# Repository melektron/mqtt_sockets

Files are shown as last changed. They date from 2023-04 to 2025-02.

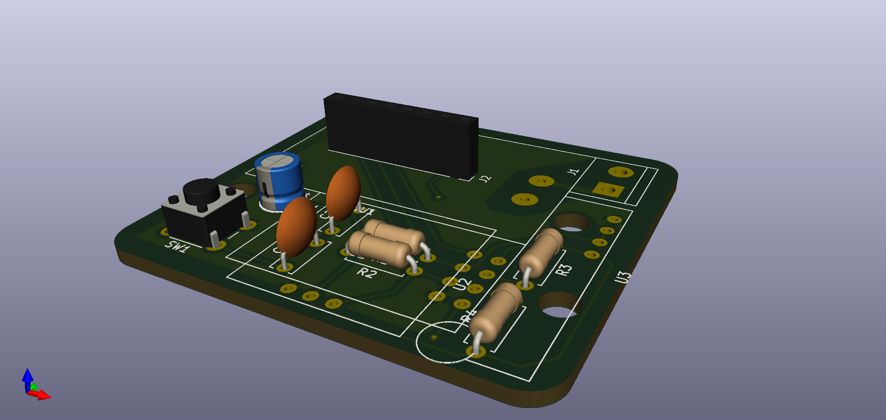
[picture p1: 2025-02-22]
hardware/WiFi-RC-Switch-Bridge_Outlet/WiFi-RC-Switch-Bridge_Outlet.png

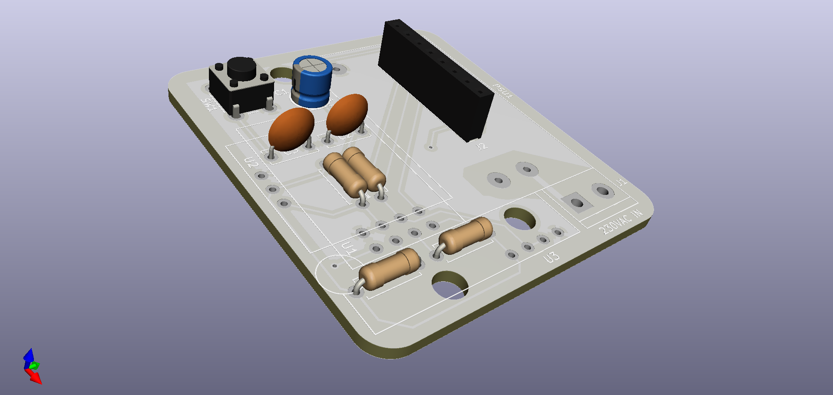
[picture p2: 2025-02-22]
hardware/WiFi-RC-Switch-Bridge_Outlet/WiFi-RC-Switch-Bridge_Outlet3.png

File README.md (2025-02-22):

# Disclaimer

This is a PlatformIO "port" of an old of an old ESP8266 Arduino project that I did several years ago.
This code is by no means clean or memory safe and there are no guarantees of it working as expected. The only reason this old project is published in this state is so I can preserve it and fix bugs that arise over time as I need this in daily production. It has been working mostly reliably but use it at your own risk. 

Note to myself:
The folder "old_code" contains all the old code and versions that came about before I used git to store the project. These are just here for historical purposes and are not to be used. 

# MQTT Sockets

This project allows an ESP8266 connected to an MQTT server through WiFi and take commands from a SmartHome system like HomeAssistant. It then parses these commands and switches 433 MHz Remote controlled sockets on or off using a 433 MHz transmitter connected to the ESP. Multiple Remote-Socket protocols are supported.

## Project structure

This is a PIO project, so it has all the usual code folders. Additionally, the ```hardware``` folder contains KiCAD projects (legacy KiCAD project structure as these are old files):
- ```hardware/WiFi-RC-Switch-Bridge_Outlet```: The main PCB containing the ESP, RF-Transceivers and an integrated AC power supply for powering the board from the wall. This is what was used in the end.
- ```hardware/WiFi-RC-Switch-Bridge_USB```: At one point there was a plan to create a version of the board powered by USB. This contains the KiCAD project for that, although it was never completed.
- ```hardware/WiFi-RC-Switch-Programmer```: A USB-to-UART adapter based on CH340G to flash the ESP on the board. This has a connector matching the pinout of the header on the main PCB. Over the years, this has been used for many other projects and purposes.

## Setup

To use the project, you need to specify WIFI secrets, fingerprints and other configuration in the ```include/secrets.h``` file. Example content:

```c
#pragma once

#define WIFI_SSID "MyHomeWifi"
#define WIFI_PSK "MyWiFiPassword"

#define MQTT_SERVER "192.168.1.13"
#define MQTT_PORT 1883
// generate the fingerprint on the server using this command:
// echo | openssl s_client -connect localhost:1883 | openssl x509 -fingerprint -noout
#define MQTT_FINGERPRINT "07 ED 59 67 2C CD 31 6C EF 27 F7 AC 38 02 07 9C 60 EC FA 0A" // this isn't used at the moment because it didn't work
#define MQTT_BASE_TOPIC "/devices/sub0/espdev2051a/"
#define MQTT_USER "deviceuser"
#define MQTT_PWD  "devicepwd"

// when using DHCP do the following
#define WIFI_DHCP

// when using static IP do the following (replace with your correct IP settings)
// when WIFI_DHCP is defined, these values are ignored
#define WIFI_STATIC_IP 192,168,1,122
#define WIFI_STATIC_ROUTER 192,168,1,1
#define WIFI_STATIC_NETMASK 255,255,255,0

```

Of course, all the information has to be replaced by data applicable to your network setup.

Note to myself:
The values needed for my setup are found in the infrastructure setup notes.

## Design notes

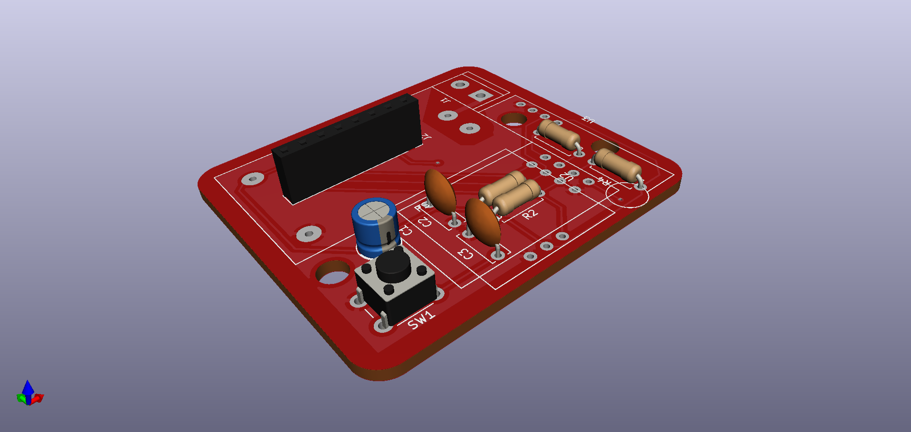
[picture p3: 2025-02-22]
hardware/WiFi-RC-Switch-Bridge_Outlet/WiFi-RC-Switch-Bridge_Outlet2.png

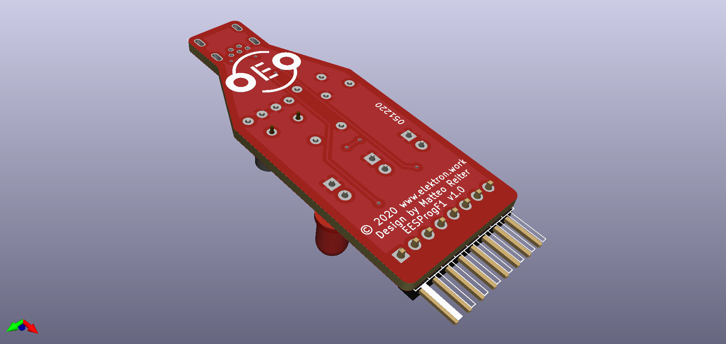
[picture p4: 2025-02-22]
hardware/WiFi-RC-Switch-Programmer/WiFi-RC-Switch-Programmer2.png

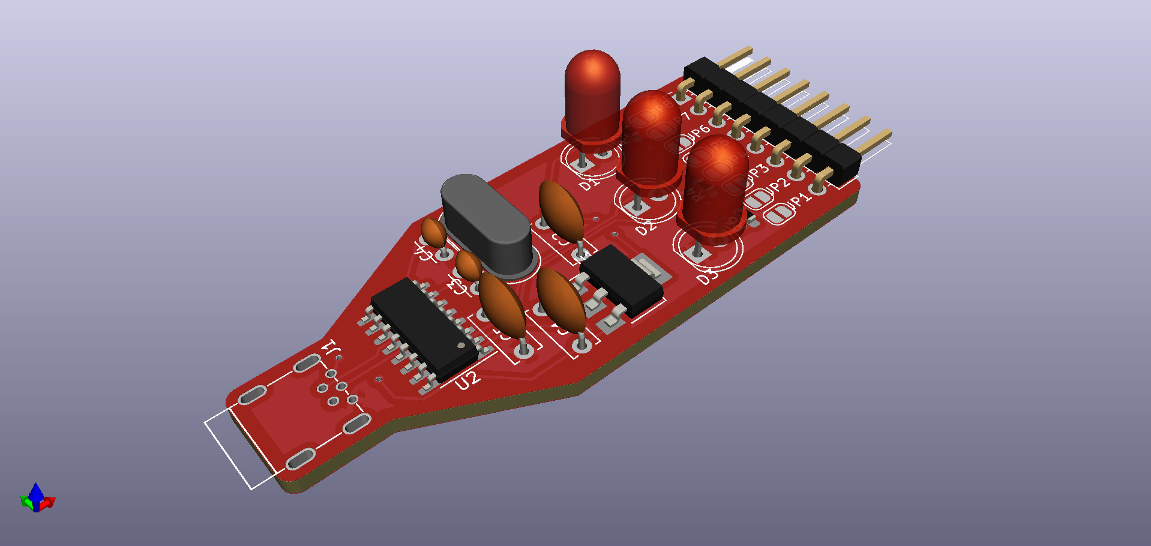
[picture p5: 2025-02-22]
hardware/WiFi-RC-Switch-Programmer/WiFi-RC-Switch-Programmer.png

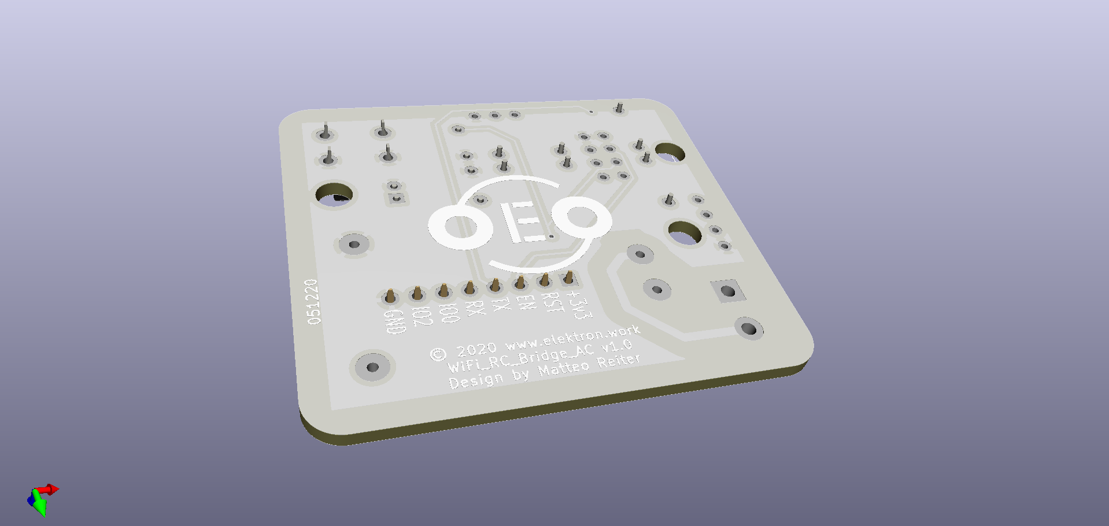
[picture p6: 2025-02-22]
hardware/WiFi-RC-Switch-Bridge_Outlet/WiFi-RC-Switch-Bridge_Outlet4.png

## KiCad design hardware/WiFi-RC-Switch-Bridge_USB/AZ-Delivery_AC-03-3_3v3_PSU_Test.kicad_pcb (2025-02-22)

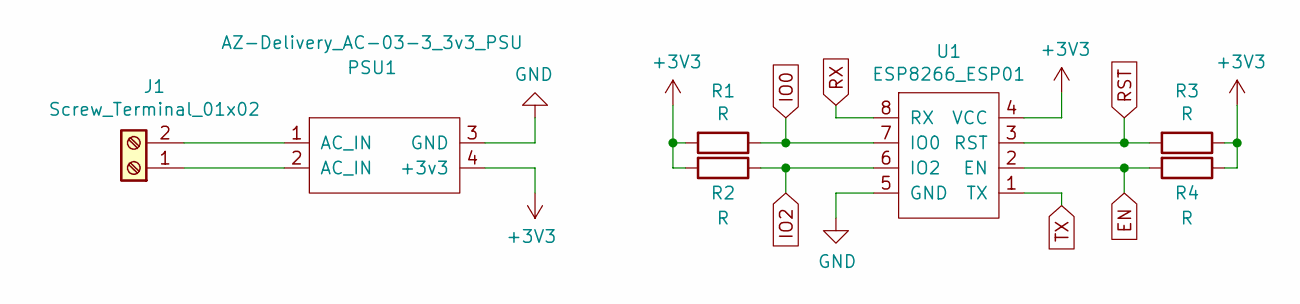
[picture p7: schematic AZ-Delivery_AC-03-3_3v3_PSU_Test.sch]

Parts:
J1: Screw_Terminal_01x02; TerminalBlock_bornier-2_P5.08mm
PSU1: AZ-Delivery_AC-03-3_3v3_PSU
R1, R2, R3, R4: R; R_Axial_DIN0207_L6.3mm_D2.5mm_P7.62mm_Horizontal
U1: ESP8266_ESP01

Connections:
+3V3: PSU1.4 (+3v3), R1.2, R2.2, R3.1, R4.1, U1.4 (VCC)
EN: R4.2, U1.2 (EN)
GND: PSU1.3 (GND), U1.5 (GND)
IO0: R1.1, U1.7 (IO0)
IO2: R2.1, U1.6 (IO2)
unnamed: J1.1, PSU1.2 (AC_IN)
unnamed: J1.2, PSU1.1 (AC_IN)
RST: R3.2, U1.3 (RST)
RX: U1.8 (RX)
TX: U1.1 (TX)

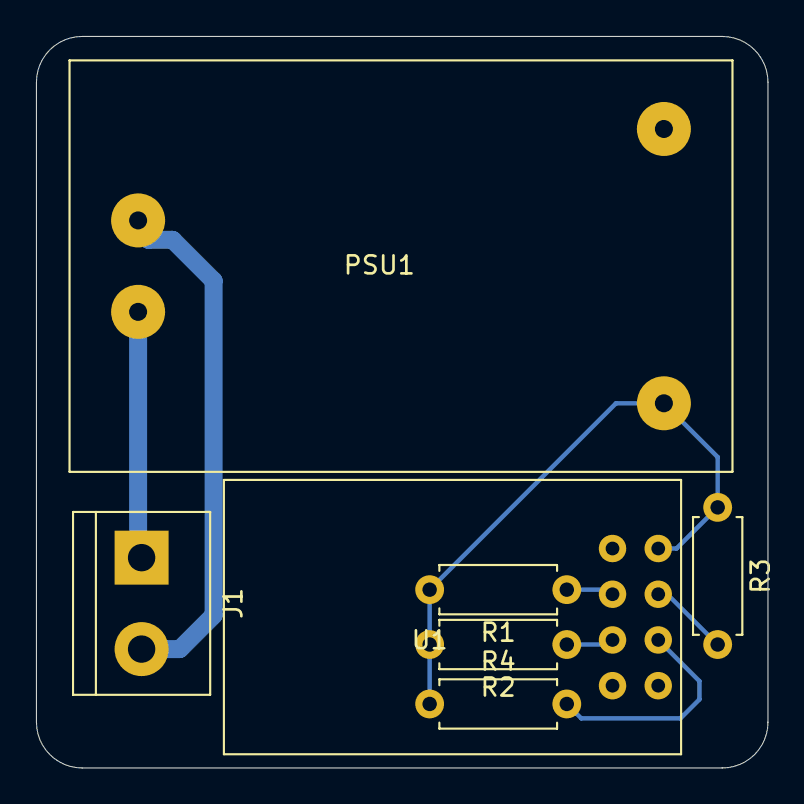
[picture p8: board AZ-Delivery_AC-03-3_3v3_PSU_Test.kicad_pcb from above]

Board: 2 copper layers, 40.6 x 40.6 mm, 7 parts (0 on the bottom side), 8 nets.

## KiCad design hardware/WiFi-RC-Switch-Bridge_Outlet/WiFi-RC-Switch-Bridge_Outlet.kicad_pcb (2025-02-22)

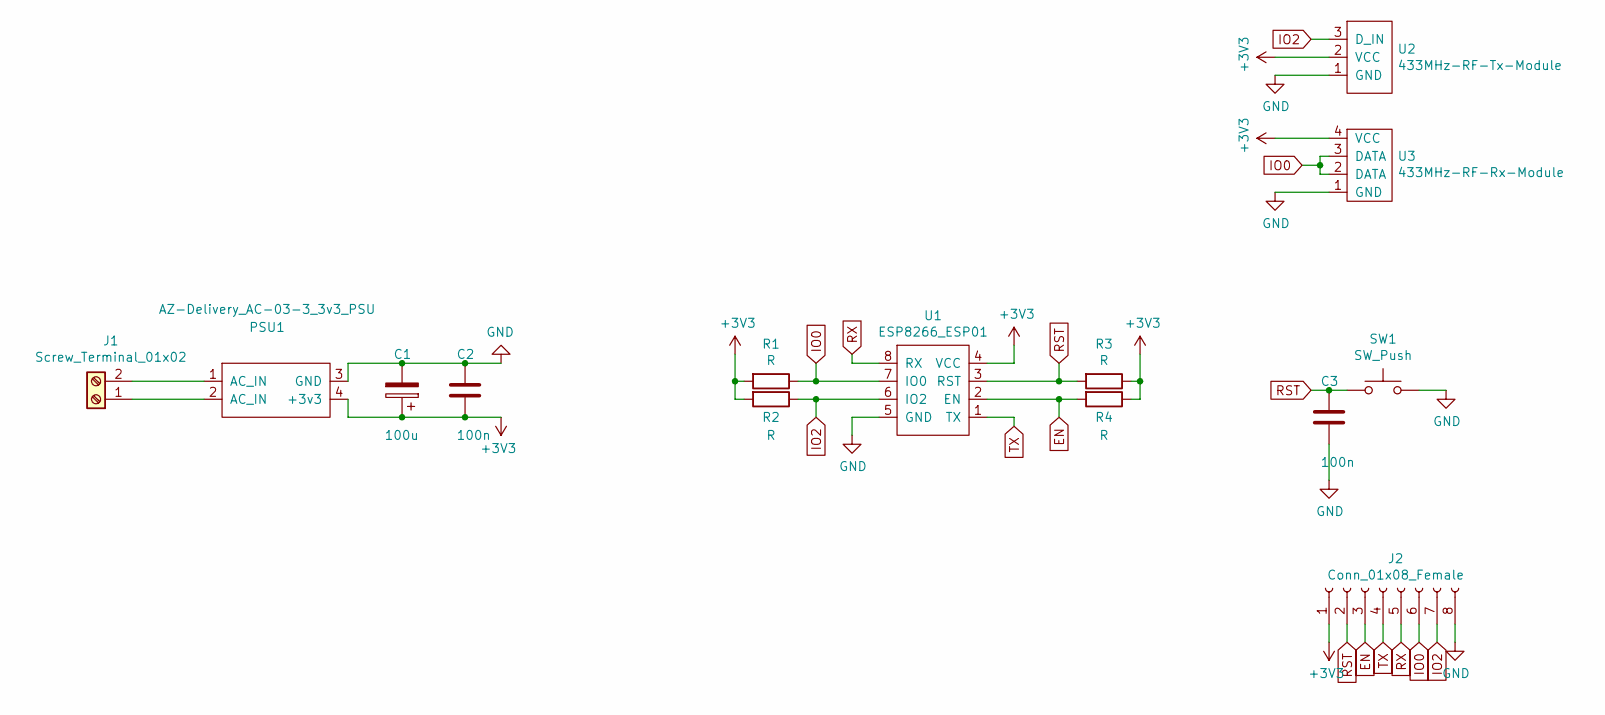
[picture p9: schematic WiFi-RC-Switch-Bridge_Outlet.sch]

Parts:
C1: 100u; CP_Radial_D5.0mm_P2.00mm
C2, C3: 100n; C_Disc_D6.0mm_W2.5mm_P5.00mm
J1: Screw_Terminal_01x02; TerminalBlock_bornier-2_P5.08mm
J2: Conn_01x08_Female; PinSocket_1x08_P2.54mm_Vertical
PSU1: AZ-Delivery_AC-03-3_3v3_PSU
R1, R2, R3, R4: R; R_Axial_DIN0207_L6.3mm_D2.5mm_P7.62mm_Horizontal
SW1: SW_Push; SW_PUSH_6mm_H5mm
U1: ESP8266_ESP01
U2: 433MHz-RF-Tx-Module; 433MHz-RF-Tx-Module_Horizontal
U3: 433MHz-RF-Rx-Module; 433MHz-RF-Rx-Module_Vertical

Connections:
+3V3: C1.1, C2.2, J2.1, PSU1.4 (+3v3), R1.2, R2.2, R3.1, R4.1, U1.4 (VCC), U2.2 (VCC), U3.4 (VCC)
EN: J2.3, R4.2, U1.2 (EN)
GND: C1.2, C2.1, C3.2, J2.8, PSU1.3 (GND), SW1.2, U1.5 (GND), U2.1 (GND), U3.1 (GND)
IO0: J2.6, R1.1, U1.7 (IO0), U3.2 (DATA), U3.3 (DATA)
IO2: J2.7, R2.1, U1.6 (IO2), U2.3 (D_IN)
unnamed: J1.1, PSU1.2 (AC_IN)
unnamed: J1.2, PSU1.1 (AC_IN)
RST: C3.1, J2.2, R3.2, SW1.1, U1.3 (RST)
RX: J2.5, U1.8 (RX)
TX: J2.4, U1.1 (TX)

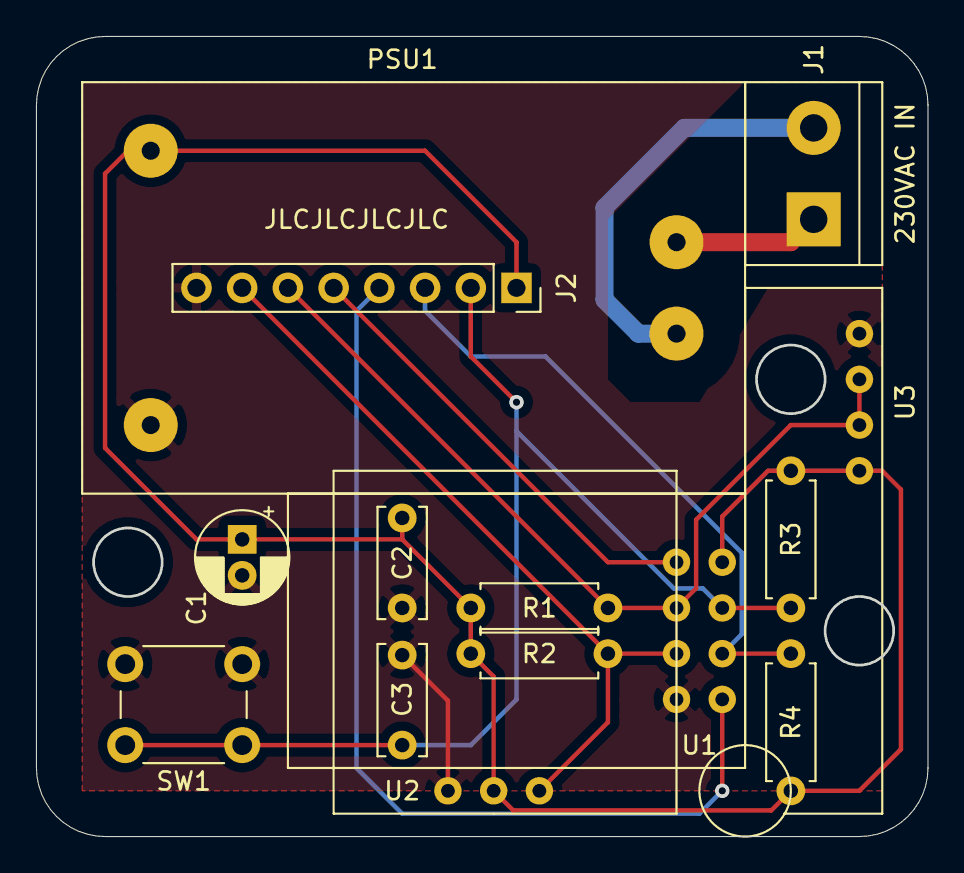
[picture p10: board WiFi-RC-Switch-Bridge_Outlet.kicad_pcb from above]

Board: 2 copper layers, 49.5 x 44.4 mm, 14 parts (0 on the bottom side), 10 nets.

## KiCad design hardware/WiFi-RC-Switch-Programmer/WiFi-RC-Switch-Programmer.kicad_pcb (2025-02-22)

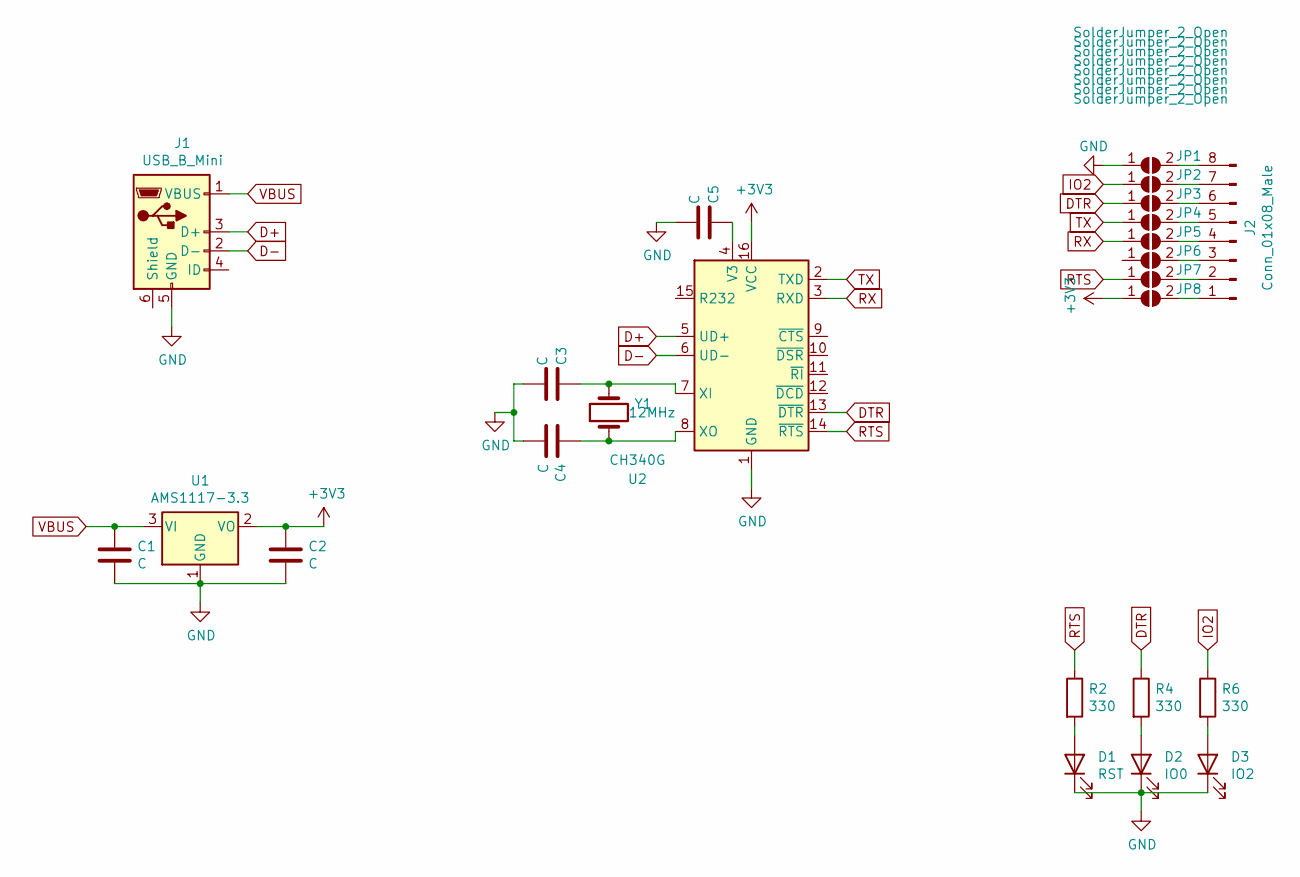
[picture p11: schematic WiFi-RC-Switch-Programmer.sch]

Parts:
C1, C2, C5: C; C_Disc_D6.0mm_W2.5mm_P5.00mm
C3, C4: C; C_Disc_D3.0mm_W2.0mm_P2.50mm
D1: RST; LED_D5.0mm
D2: IO0; LED_D5.0mm
D3: IO2; LED_D5.0mm
J1: USB_B_Mini; USB-MiniB_LCSC-C46398
J2: Conn_01x08_Male; PinHeader_1x08_P2.54mm_Horizontal
JP1, JP2, JP3, JP4, JP5, JP6, JP7, JP8: SolderJumper_2_Open; SolderJumper-2_P1.3mm_Open_RoundedPad1.0x1.5mm
R2, R4, R6: 330; R_0603_1608Metric_Pad0.98x0.95mm_HandSolder
U1: AMS1117-3.3; SOT-223-3_TabPin2
U2: CH340G; SOIC-16_3.9x9.9mm_P1.27mm
Y1: 12MHz; Crystal_HC49-4H_Vertical

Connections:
+3V3: C2.1, JP8.1 (A), U1.2 (VO), U2.16 (VCC)
D+: J1.3 (D+), U2.5 (UD+)
D-: J1.2 (D-), U2.6 (UD-)
DTR: JP3.1 (A), R4.1, U2.13 (~DTR)
GND: C1.2, C2.2, C3.2, C4.2, C5.2, D1.1 (K), D2.1 (K), D3.1 (K), J1.5 (GND), JP1.1 (A), U1.1 (GND), U2.1 (GND)
IO2: JP2.1 (A), R6.1
unnamed: C3.1, U2.7 (XI), Y1.2
unnamed: C4.1, U2.8 (XO), Y1.1
unnamed: C5.1, U2.4 (V3)
unnamed: D1.2 (A), R2.2
unnamed: D2.2 (A), R4.2
unnamed: D3.2 (A), R6.2
unnamed: J2.1, JP8.2 (B)
unnamed: J2.2, JP7.2 (B)
unnamed: J2.3, JP6.2 (B)
unnamed: J2.4, JP5.2 (B)
unnamed: J2.5, JP4.2 (B)
unnamed: J2.6, JP3.2 (B)
unnamed: J2.7, JP2.2 (B)
unnamed: J2.8, JP1.2 (B)
RTS: JP7.1 (A), R2.1, U2.14 (~RTS)
RX: JP5.1 (A), U2.3 (RXD)
TX: JP4.1 (A), U2.2 (TXD)
VBUS: C1.1, J1.1 (VBUS), U1.3 (VI)

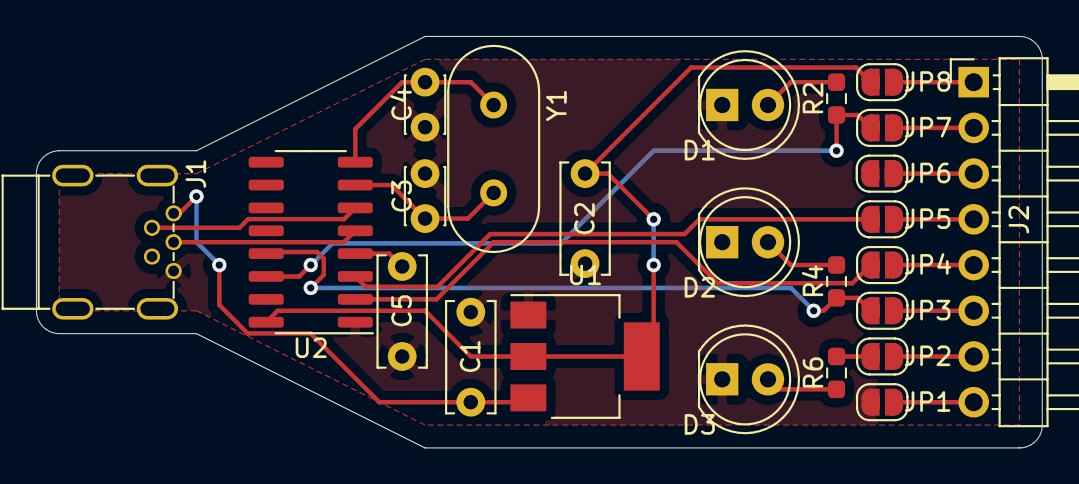
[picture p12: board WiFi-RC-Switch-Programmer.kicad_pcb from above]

Board: 2 copper layers, 55.9 x 22.9 mm, 24 parts (0 on the bottom side), 24 nets.

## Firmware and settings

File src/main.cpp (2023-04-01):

/*
MQTT-Remot-Switches for ESP8266
Written by Matteo Reiter, 14.12.2020
© 2020 www.elektron.work
More information about this project
and the home automation project this is
part of can be found on my website:
## TBD

This code was written by Matteo Reiter
and is based on the MQTT example code 
writte by BitBastelei: www.adlerweb.info

This Sketch is open source and you are
allowed to republish and modifie it 
as long as credits are given


This Sketch does:
 * Connect to WiFi and to a MQTT Broker on the local network
 * Subscribe to a base topic and convert light controll messages 
   in the json format on this topic to
   433MHz signals for remote switches/sockets
 * send theses messages via a 433MHz Transmitter connected to pin 2
   (pin can be changed in <rctx> variable) through different
   protocols depending on the subtopic


Error Messages:
This code will inform you of an internal Error when trying to process a command
received via MQTT. It will print the error messages to serial
as well as sending an error message via MQTT.

The messages consist of an error code and an error Message.
The errror code tells the type of error, the message is 
a string that is readable to users and can tell more about
what exactly caused this error.
Here is the table of possible error codes:

1 = Invalid Topic (some part of the Topic that a command was received over is invalid)
2 = Static buffer size exceeded (Some part of the message (can be topic or payload) is to large to fit in the static buffer)
3 = Json error (something went wront during the deserializatino of the json payload)
4 = Invalid Message (this occurs when the value of the message is not what the system expects, e.g. a requires json key is messing. This error does not occur when the json is corrupted!)

 */



#include <ESP8266WiFi.h>
#include <ESP8266mDNS.h>
#include <PubSubClient.h>
#include <RCSwitch.h>
#include <ArduinoJson.h>

#include "secrets.h"


int rctx = 2;                                     // Pin for the RC-Transmitter
int rcrx = 0;                                     // Pin for the RC-Receiver (not jet implemented)
int WiFiConnected = 2;                            // Pin for an LED that blinks while WiFi is connecting

const char* cfg_wifi_ssid = WIFI_SSID;            // WiFi SSID
const char* cfg_wifi_pwd = WIFI_PSK;              // WiFi Password

const char* mqtt_server = MQTT_SERVER;         // MQTT server
const unsigned int mqtt_port = MQTT_PORT;              // MQTT port
const char* mqtt_user =   MQTT_USER;              // MQTT user
const char* mqtt_pass =   MQTT_PWD;               // MQTT passwd
uint32_t conCheckInterval = 1000000;              // Each x loopcycles the connecttino to the server will be checked


// the following variables/arrays are buffers for various remote-switch/socket data protocols
// for the dip-switch remote-switch/socket protocol
char systemCode[6] = "00000";                      // some char array the save the Remote-Switch/Socket system code
char unitCode[6] = "00000";                        // some char array the save the Remote-Switch/Socket unit code

// for remote-switches/sockets protocol by Intertechno
char intertechno_id[3][10];
char family = 'b';
char group_char[2] = "3";
uint8_t group_int = 3;
char device_char[2] = "3";
uint8_t device_int = 2;

// for rotaty/sliding switch remote-switch/socket protocol
char switch1_char = '1';
uint8_t switch1_int = 1;
char switch2_char = '4';
uint8_t switch2_int = 4;



char remote_switch_id[10];                        // for some remote-switch/socket types I need to use strtok() to fetch the switch/socket id. Therefor i can first copy it into this array, so the original in the subtopic_list will not get destroyed
char stateBuf[5] = "off";                         // buffer to store the raw state value
char stateCode = '0';                             // come char to store the Remote-Switch/Socket state (1/0, ON/OFF)
bool messageInvalid = false;                      // message Invalid flag


// some buffers and definitions for topics and messages
#define TOPIC_BUF_L 300                                                 // lenght of the topic buffer in characters (a value of 300 means, topics are not allowed to be over 300 characters long or the programm might crash due to buffer overflow as strcpy_s is not a thing in arduino
#define MSG_BUF_L 100                                                   // lenght of the message buffer in characters (a value of 100 means, messages are not allowed to be over 100 characters long or the programm might crash due to buffer overflow as strcpy_s is not a thing in arduino
#define MAX_SUB_TOPICS 10                                               // maximum number of subtopics 
#define SUB_TOPIC_BUF_L 50                                              // lenght of the subtopic buffer in characters (a value of 50 means, subtopics are not allowed to be over 50 characters long or the programm might crash due to buffer overflow as strcpy_s is not a thing in arduino

const char *base_topic = MQTT_BASE_TOPIC;                        // set the base topic (should end with "/")
char base_topic_cpy[100];                                               // momory pool for copy of base topic
uint8_t nr_base_subtopics;                                              // the number of subtopics the base topic has (will be calculated by the programm automatically)

char topic_buf[TOPIC_BUF_L];                                            // topic buffer
char topic_cpy[TOPIC_BUF_L];                                            // copy of topic buffer (needs to be a copy and not a pointer as the strtok() function manipulates the source string so it needs to be a copy of the original unless you don't need the original anymore afterwards
char *topicsplit;                                                       // a pointer to a section of the topic created by strtok()
const char *topic_delimiters = "/";                                           // the delimiter(s) who seperate subtopics
char subtopic_list[MAX_SUB_TOPICS][SUB_TOPIC_BUF_L];                    // buffer to store a list of all the subtopics of a message
uint8_t subtopic_counter = 0;                                           // counter to count how many subtopics the topic of a message has

char topic_out_buf[TOPIC_BUF_L];                                        // buffer for output topic

char msg_buf[MSG_BUF_L];                                                // message buffer
char msg_cpy[MSG_BUF_L];                                                // copy of the message buffer (needs to be a copy and not a pointer as the strtok() function manipulates the source string so it needs to be a copy of the original unless you don't need the original anymore afterwards

char msg_out_buf[MSG_BUF_L];                                            // buffer for output payload

StaticJsonDocument<MSG_BUF_L*2> msg_doc;                                // create a static json document for the message and allocate it double the memory of the message buffer just to be sure

// some tmp variables
char tmpchar;
char tmponechararray[2];                                                // we need to bytes to store a string with one character, because there will be an extra NULL byte for termination


// fingerprint for ssl (not jet working)
//echo | openssl s_client -connect localhost:1883 | openssl x509 -fingerprint -noout
const char* mqtt_fprint = MQTT_FINGERPRINT;


// IP configuration for static IP setup, ignore or comment out if you are using DHCP
// if you are not sure what you are using, you are probably using DHCP
#ifndef WIFI_DHCP
IPAddress ip(WIFI_STATIC_IP);                      // static IP address for the ESP
IPAddress router(WIFI_STATIC_ROUTER);                    // IP address of the Wifi router
IPAddress netmask(WIFI_STATIC_NETMASK);                 // static netmask of your network
#endif

// Initialize Classes, create objects
WiFiClientSecure espClient;                       // WiFiClientSecure class, needed for communication
PubSubClient client(espClient);                   // PubSubClient class, needed for MQTT
RCSwitch mySwitch = RCSwitch();                   // RC-Swich class, needed for Remote-Switches/Sockets


void raiseError(int rc, const char *errorMsg);
void callback(char* topic, uint8_t* payload, size_t length);
void secureConnect();


void setup() {
  // Initialize Serial(UART) connection for debugging
  Serial.begin(115200);                             // Initializing UART for a baud rate of 115200, you can change it to your prefered baud rate if you want.
  Serial.println("MQTT-Remote-Switches");           // Printing a title to the Serial connection
  
  // set up wifi config
  WiFi.mode(WIFI_STA);                             // We are using the ESP as a WiFi client
#ifndef WIFI_DHCP
  WiFi.config(ip,router,netmask);                  // This sets up static IP addresses, comment out if you are using DHCP. If you are not sure, you are probably using DHCP.
#endif
  WiFi.begin(cfg_wifi_ssid, cfg_wifi_pwd);         // Connect to WiFi using the set SSID and password
  
  // wait until wifi is connected
  while (WiFi.status() != WL_CONNECTED) {          // While the WiFi is not connected
    delay(500);                                    // Wait half a second (500ms)
    Serial.print(".");                             // Print a dot to the Serial connection
    digitalWrite(WiFiConnected, !digitalRead(WiFiConnected)); // Invert the state of I/O pin 2, which is the builtin LED on the ESP01s (not ESP01)
  }

  // now that pin 2 is no longer needed for WiFi status, we can initialize the Remote-Switches
  mySwitch.enableTransmit(rctx);
  
  // output some usefull debug information
  Serial.println();
  Serial.println("WiFi connected");
  Serial.println("IP address: ");
  Serial.println(WiFi.localIP());                  // Print the ESP's IP address, usefull if you are usin DHCP, if you are using a static IP config, it will allways be the defined IP of the ESP
  Serial.println("MAC Address:");
  Serial.println(WiFi.macAddress());               // Print the MAC address of the ESP, usefull if you have access controll on your router and you want to allow the ESP
  
  // set the ca certificate for ssl (not jet working
  //espClient.setCACert(test_root_ca);

  // this turns of SSl. Comment out if you are using ssl (currently ssl doesn't work so I had to uncomment this line)
  espClient.setInsecure();
  
  // Configura MQTT class
  client.setServer(mqtt_server, mqtt_port);        // Set MQTT server and port
  client.setCallback(callback);                    // set the functino called when new data is available
  
  // attempting to connect to the server
  while (!client.connected()) {                                           // while not connected to MQTT server
    Serial.print("Attempting MQTT connection...");                        // print debug line
    secureConnect();                                                      // jump to secureConnect() function to try to establish a secure connection (when espClient.setInsecure() is enabled, this will not create a secure connection)
    if (client.connect(mqtt_user, mqtt_user, mqtt_pass)) {                // try to connect to the MQTT server
      Serial.println("connected");                                        // print debug line
      char subsctopic[strlen(base_topic) + 1];
      strcpy(subsctopic, base_topic);
      strcat(subsctopic, "#");
      Serial.print("subscriging to: ");
      Serial.println(subsctopic);
      client.subscribe(subsctopic);                                       // subscribe to the base topic
    }else{                                                                // if connection failed:
      Serial.print("failed, rc=");                   
      //
      Serial.print(client.state());                                       // print some debug info
      Serial.println(" try again in 5 seconds");                          //    
      delay(5000);                                                        // wait 5 seconds befor trying again.
    }
  }

  // before we go the the loop, we calculate some constant values that are needet later, so they don't have to be calculatet for every message
  
  // Number of subtopics in the basetopic
  // By isolating all the subtopics and then iterating throught them using the strtok funktin, we can count how many subtopics there are.
  char *ptr;                                                  // create a pointer
  
  // copying the base topic to the base_topic_cpy array, because the strtok() function modifies the original string
  strcpy(base_topic_cpy, base_topic);
  ptr = strtok(base_topic_cpy, topic_delimiters);             // initialize the strtok function and isolate the first subtopic
  nr_base_subtopics = 0;                                      // set the countet subtopics to zero
  while(ptr != NULL){                                         // while there are subtopics
    ptr = strtok(NULL, topic_delimiters);                     // iterate to the next subtopic
    nr_base_subtopics++;                                      // and increment the counter
  }
  Serial.print("Nr of subtopics in base topic: ");
  Serial.println(nr_base_subtopics);
}


void raiseError(int rc = 0, const char *errorMsg = "NO_ERR"){
  // This function will be called when an error schould be sent out. So you can change the error messagin code here once and it apply to every error message
  Serial.print("#========== Exeception ==========#\n\rrc = ");
  Serial.print(rc);
  Serial.print(" >> ");
  Serial.println(errorMsg);
  Serial.println("#================================#");
}



void callback(char* topic, uint8_t* payload, size_t length) {
  // print some log info
  Serial.print("Message arrived [");
  Serial.print(topic);
  Serial.println("]");

  // load the topic from the callback pointer to the topic buffer
  int topiclen = strlen(topic);                                           // store the size of the topic
  Serial.print("Topic size: ");
  Serial.print(topiclen);
  Serial.println(" characters");
  if(topiclen > TOPIC_BUF_L){                                             // if the topic is to long for the buffer
    raiseError(2, "Topic to long for static buffer");                     // rais an error message
    return;                                                               // and break the function
  }
  strcpy(topic_buf, topic);                                               // copy the topic from the callback pointer to the topic buffer
  strcpy(topic_cpy, topic);                                               // copy the topic from the callback pointer to the second topic buffer

  Serial.print("Payload size: ");
  Serial.print(length);
  Serial.println(" characters");
  
  // load the message into a char array
  if(length > MSG_BUF_L){                                                 // if the topic is to long for the buffer
    raiseError(2, "Payload to long for static buffer");                   // rais an error message
    return;                                                               // and break the function
  }
  for (size_t i = 0; i < length; i++) {                                      // otherwise load the payload from a byte array into the char array msg_buf
    msg_buf[i] = (char)payload[i];
  }
  msg_buf[length] = '\0';                             // add terminator byte the the end of the char array
  strcpy(msg_cpy, msg_buf);                                               // copy the payload from the callback pointer to the second payload buffer
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
void loop() {
  // The MQTT loop function is called in order to check for new incomming packets
  client.loop();
  
  // Every <conCheckInterfal> loop cycles the connectino to the server will be checked and the esp will reboot if eighter the 
  // WiFiClientSecure connection or the PubSubClient connectinos have failed.
  if(loopcounter >= conCheckInterval){
    Serial.print("Connection check: ");
    if(!client.connected()){
      Serial.println("Connection lost! Rebooting...");
      Serial.flush();
      ESP.restart();
    }else{
      Serial.println("Connection good");
    }
    loopcounter = 0;
  }
  loopcounter++;
}

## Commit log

2023-04-01 fixed integer comparison warnings
    [main.cpp]
2025-02-22 retrospectively added old hardware design files
    [AZ-Delivery_AC-03-3_3v3_PSU_Test.kicad_pcb, AZ-Delivery_AC-03-3_3v3_PSU_Test.sch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]
